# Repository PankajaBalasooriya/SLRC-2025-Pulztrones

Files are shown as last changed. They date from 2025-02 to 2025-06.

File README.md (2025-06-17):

# 🤖 SLRC Vision-Based Autonomous Robot (1st Runner-up)

This repository contains the design and codebase of our autonomous robot, developed for the **Sri Lankan Robotics Challenge (SLRC)**. Our robot was powered by a ** STM32 microcontroller and Raspberry Pi**, and it earned **1st Runner-up** in the national university category.

---

## 📸 Preview
<center>
<table>
  <tr>
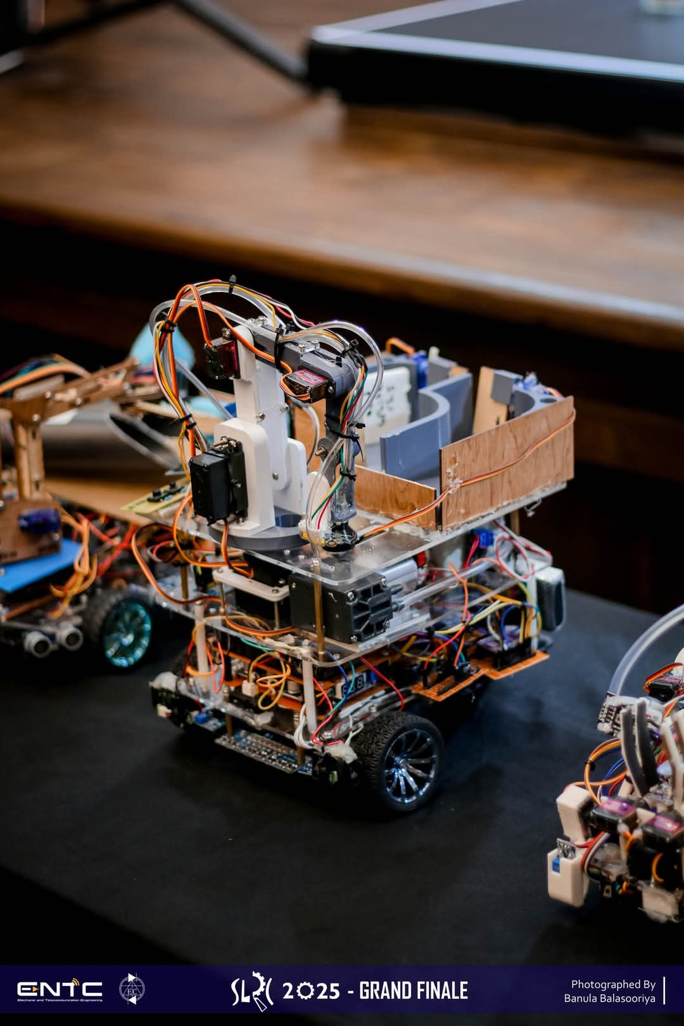
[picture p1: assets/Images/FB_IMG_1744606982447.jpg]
    <td>
  <br>
  <em>Figure 1: Final robot design for SLRC 2024</em></td>
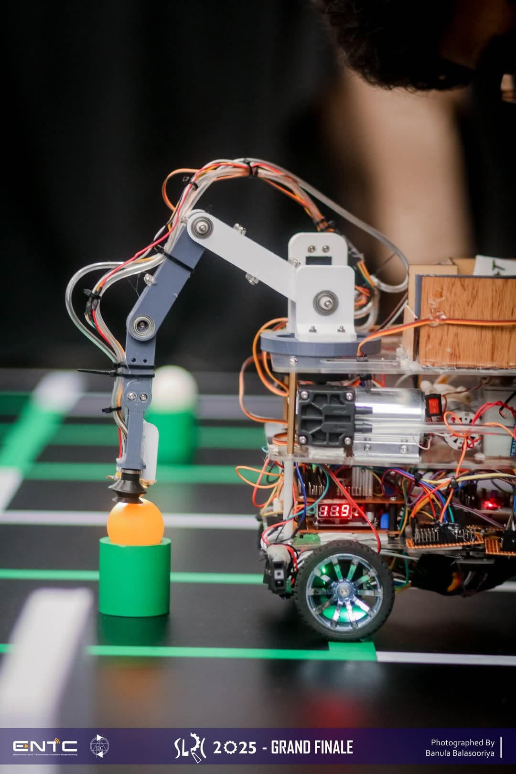
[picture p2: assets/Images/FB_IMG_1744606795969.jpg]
    <td>
  <br>
  <em>Figure 2: Color Detection using Robot Arm</em></td>
  </tr>
</table>
</center>
<p align="center">
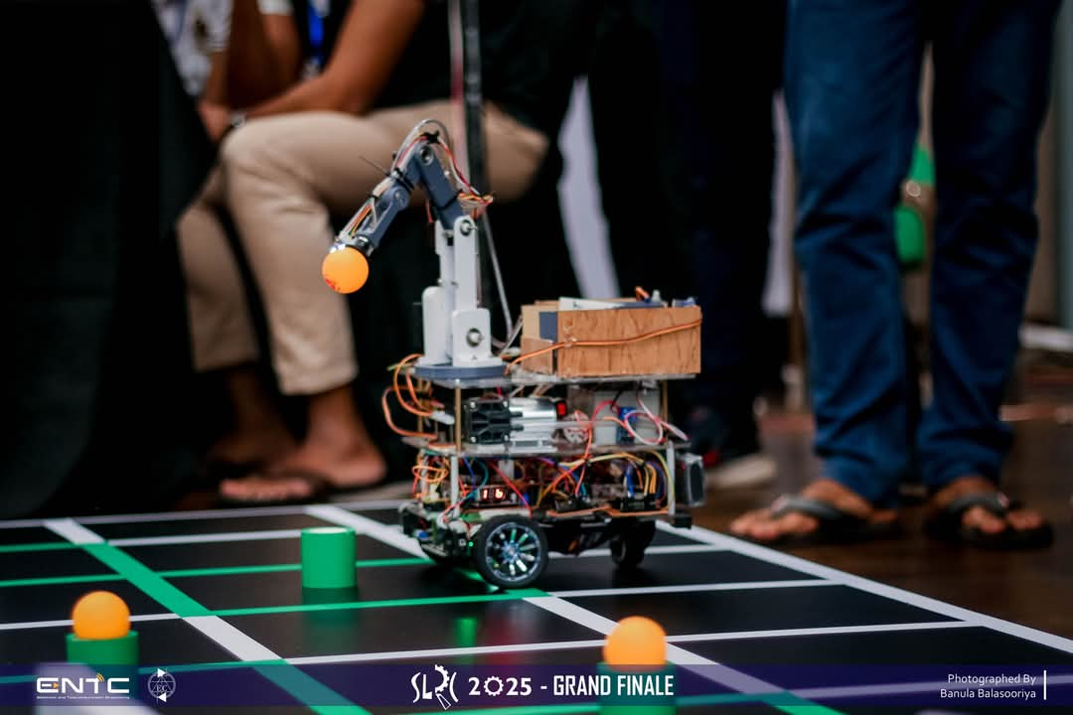
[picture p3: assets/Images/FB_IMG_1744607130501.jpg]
  
  <br>
  <em>Figure 3: Picking Balls using Robot Arm</em>
</p>

<p align="center">
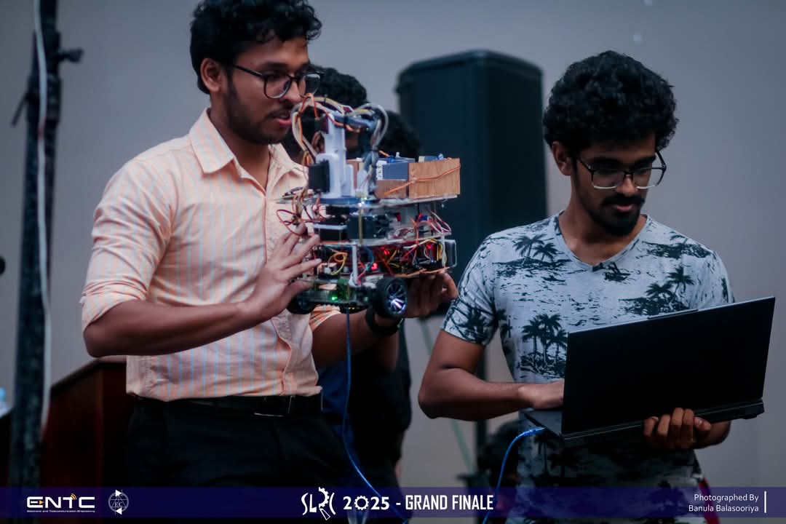
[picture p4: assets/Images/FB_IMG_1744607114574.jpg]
  
  <br>
  <em>Figure 4: Progrmming the hidden task</em>
</p>

<p align="center">
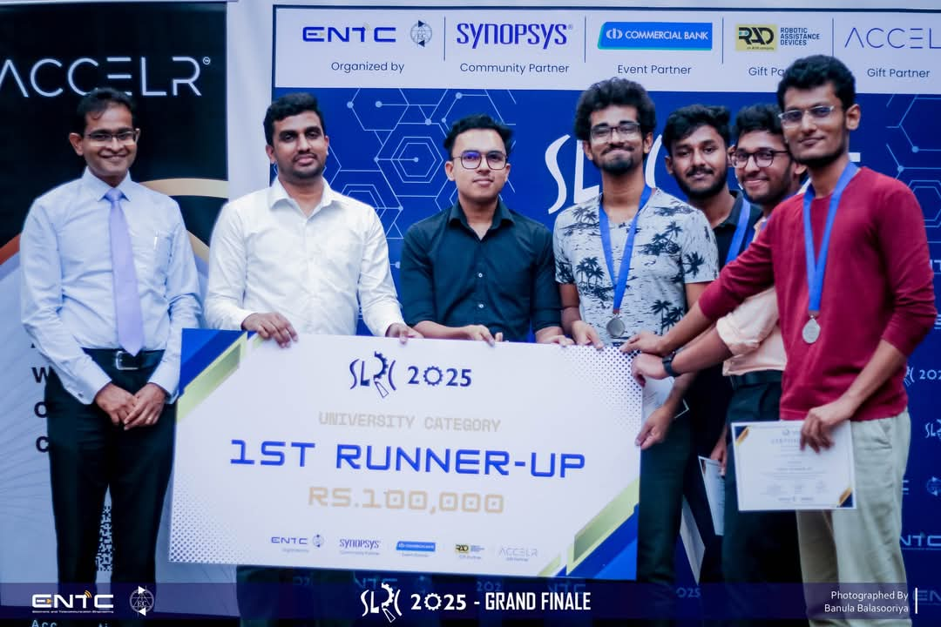
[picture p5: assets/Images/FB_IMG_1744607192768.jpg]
  
  <br>
  <em>Figure 5: Awarding Ceramony</em>
</p>

---

## 🚀 Key Features

- 🔧 Real-time control with **STM32 microcontroller**
- 🎯 Vision-based object tracking using **OpenCV** - For Elimination Round only
- 🔁 PID-based motor control
- 🧠 Modular software structure (Python + Embedded C)
- 🖥️ UART-based communication between Pi and STM32

---

## 🛠️ Hardware Components

| Component | Description |
|---|---|
| Raspberry Pi | High-level processing (vision, logic) |
| STM32 MCU | Low-level motor control |
| Motor Drivers | L298N Dual H-Bridge |
| Camera Module | Raspberry Pi Camera Module v2 |
| Chassis & Motors  | Custom-built 2WD platform |
| Power Supply | 11.1V LiPo Battery |

---

📅 **Last Updated - Codes:** `[06-04-2025]`
📅 **Last Updated - Designs:** `[06-04-2025]`

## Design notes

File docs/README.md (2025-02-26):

# 📚  Datasheets and References

| **Component** | **Datasheet / Reference Link** |
|---|---|
| **STM32F446RE** (MCU) Datasheet | [STM32F446RE Datasheet](https://www.st.com/resource/en/datasheet/stm32f446re.pdf) |
| **STM32F446RE** (MCU) User Manual | [STM32F446RE User Manual](https://www.st.com/resource/en/user_manual/um1724-stm32-nucleo64-boards-mb1136-stmicroelectronics.pdf) |
| **STM32F446RE** (MCU) Reference | [STM32F446RE Reference](https://os.mbed.com/platforms/ST-Nucleo-F446RE/) |
| **Raspberry Pi 4B** | [Raspberry Pi Datasheet](https://datasheets.raspberrypi.com/rpi4/raspberry-pi-4-datasheet.pdf) |
| **Raspberry Pi 4B** Documentation | [Raspberry Pi 4B Docs](https://www.raspberrypi.com/documentation/) |
| **Raspberry Pi 4B** BCM2711 | [BCM2711 Datasheet](https://datasheets.raspberrypi.com/bcm2711/bcm2711-peripherals.pdf) |
| **Raspberry Pi 4B** Schematics | [Raspberry Pi 4B Schematics](https://datasheets.raspberrypi.com/rpi4/raspberry-pi-4-reduced-schematics.pdf) |
| **Raspberry Pi 4B** GPIO | [Raspberry Pi GPIO](https://dnycf48t040dh.cloudfront.net/fit-in/840x473/GPIO-diagram-Raspberry-Pi-4.png) |
|||
| **PCA9685 16-Ch 12-bit PWM I2C Servo Motor Driver**  | [Adafruit Datasheet](https://cdn-learn.adafruit.com/downloads/pdf/16-channel-pwm-servo-driver.pdf) |
| **PCA9685 Datasheet**  | [PCA9685 Datasheet](https://github.com/henriheimann/stm32-hal-pca9685/blob/master/datasheet/PCA9685.pdf) |

For any updates or additional references, please keep this file updated. 🚀

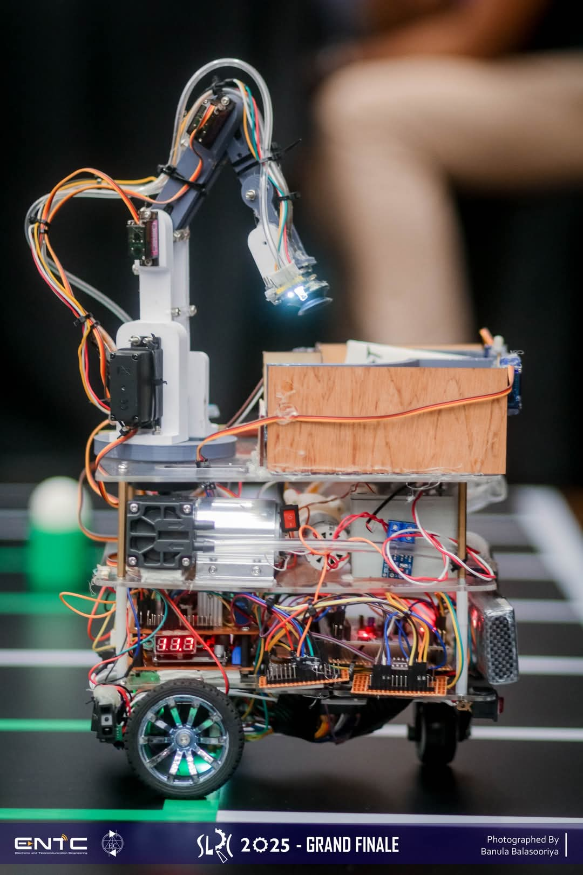
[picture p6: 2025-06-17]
assets/Images/FB_IMG_1744607050026.jpg

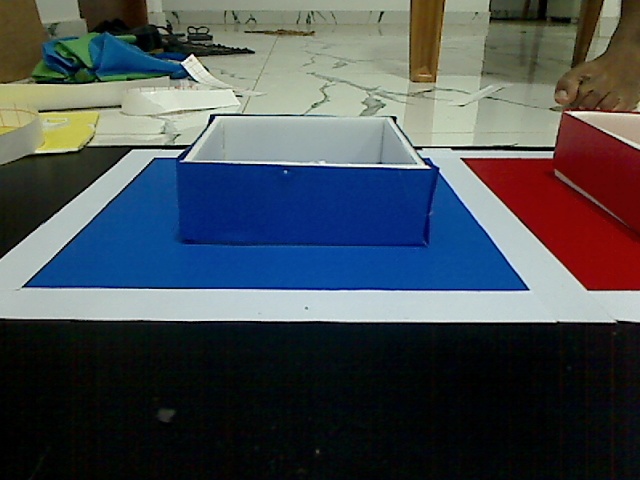
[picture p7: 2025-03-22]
software/RPI/captured_image_4.jpg

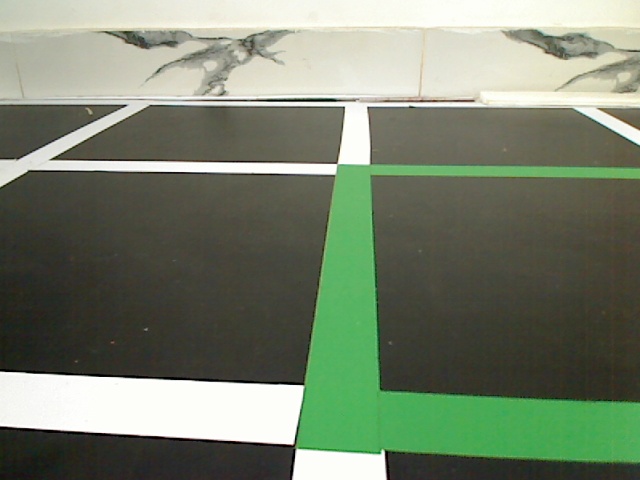
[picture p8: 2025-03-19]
software/RPI/captured_image_2.jpg

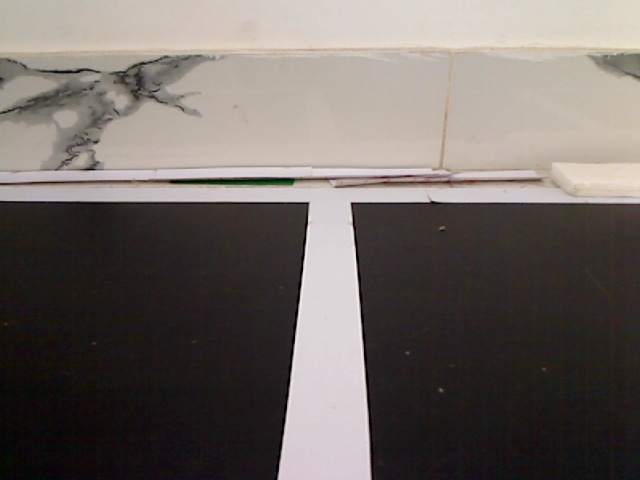
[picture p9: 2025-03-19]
software/RPI/captured_image_3.jpg

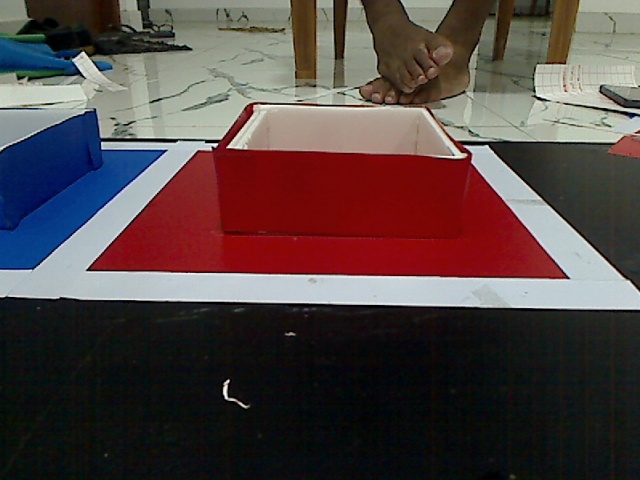
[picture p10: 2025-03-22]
software/RPI/captured_image_6.jpg

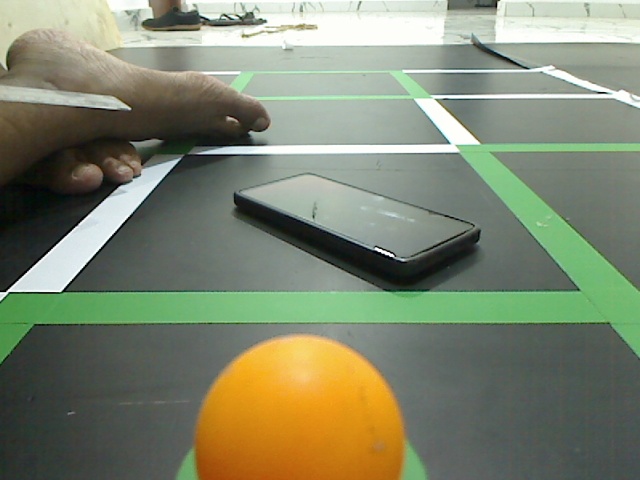
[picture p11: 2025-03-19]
software/RPI/captured_image.jpg

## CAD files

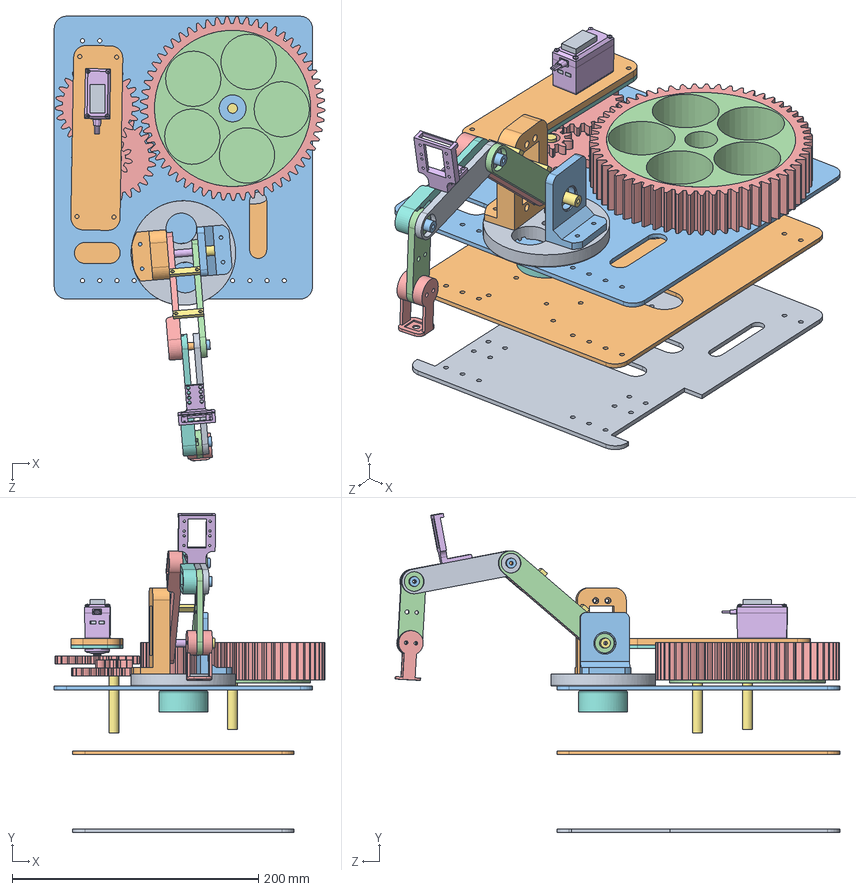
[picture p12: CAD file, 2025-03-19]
Designs/Mian Design/SLRC-2025-robot.SLDASM
219.9 x 259.3 x 361.5 mm
Bottom-plate
Mid-plate
Top-plate
Storage Gear
spur gear_ai x 4
gear bearing shaft x 2
vertical servo mount low gear
base
big servo holder
part A
part C
part B
part E
part F
Part G
Part I
Part J
part K x 2
Part L
part M
camera holder
part N x 2
Part P
MG90-servo
small servo mount

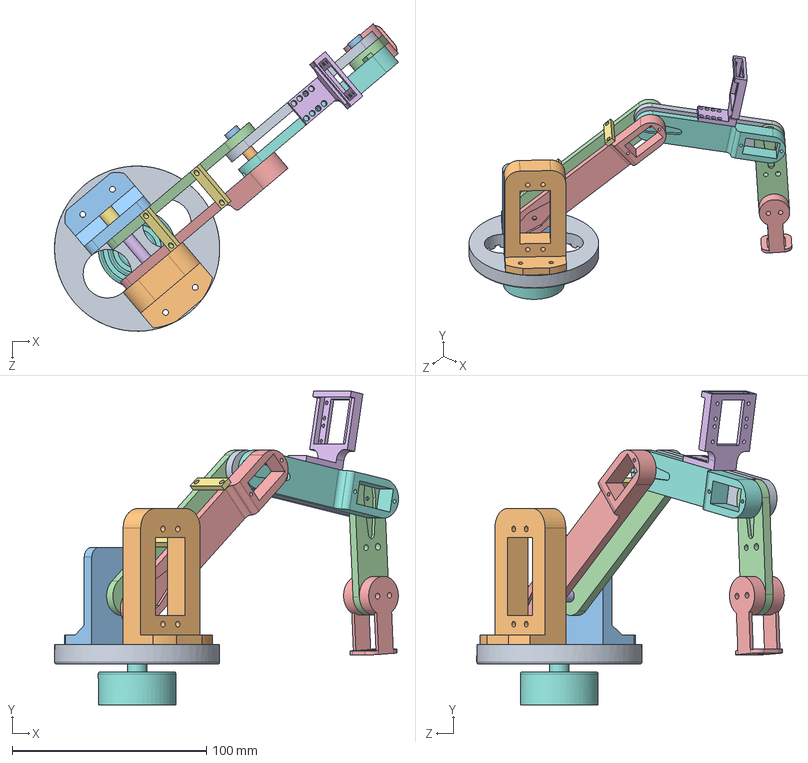
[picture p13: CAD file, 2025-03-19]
Designs/Arm design/Assem1.SLDASM
176.9 x 161.4 x 158.2 mm
base
big servo holder
part A
part C
part B
part E
part F
Part G
Part I
Part J
part K x 2
Part L
part M
camera holder
part N x 2
Part P

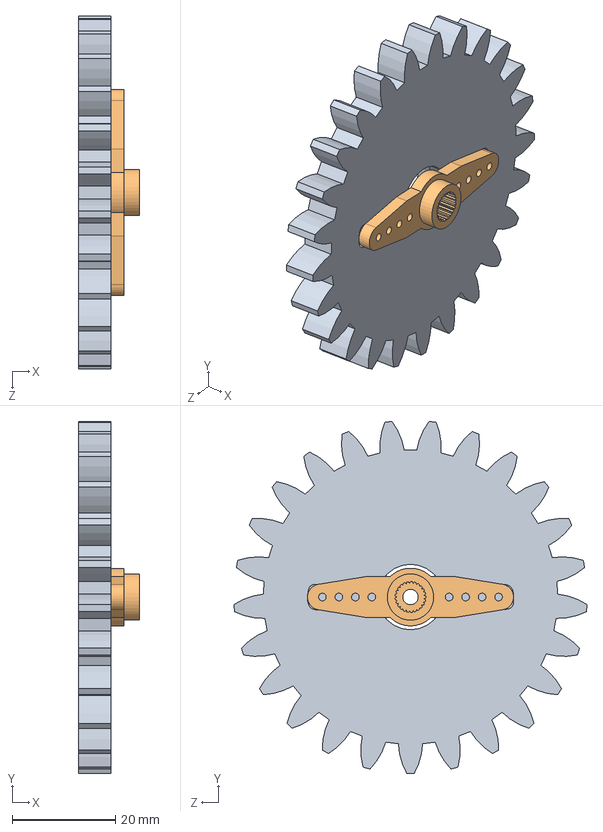
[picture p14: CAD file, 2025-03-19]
Designs/Ball Storage/Gear with servo connector grove.SLDASM
11.9 x 68.4 x 68.5 mm

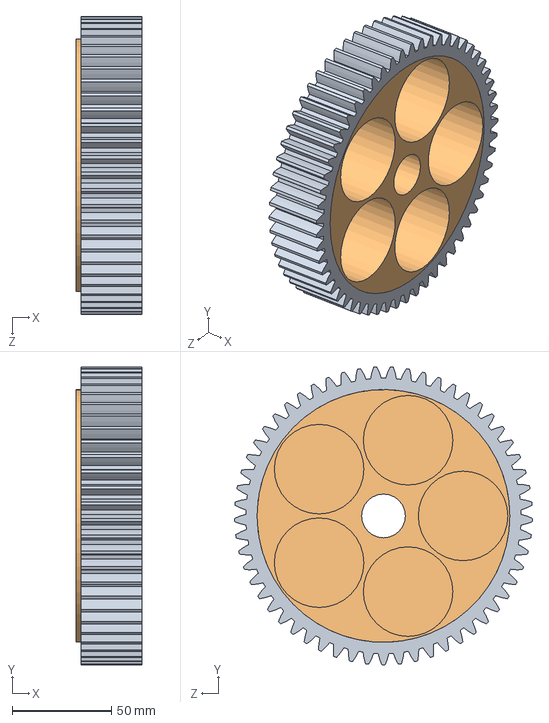
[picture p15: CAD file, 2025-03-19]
Designs/Ball Storage/Boll Storage gear Assemblt.SLDASM
33.0 x 149.8 x 149.8 mm
spur gear_ai
Storage Gear

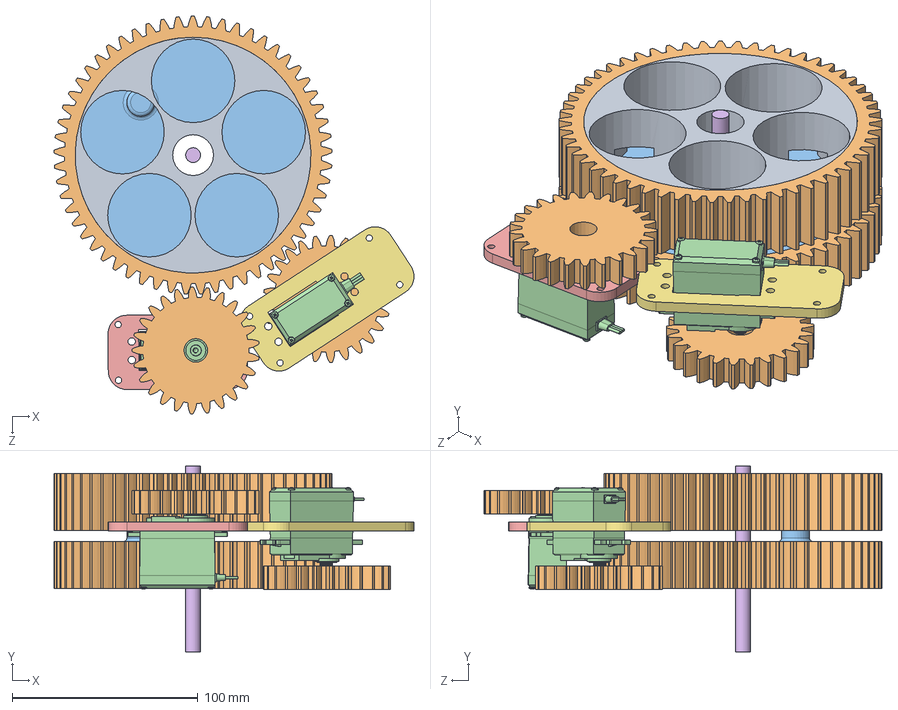
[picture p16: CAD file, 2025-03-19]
Designs/Ball Storage/Storage Gear Ass.SLDASM
193.9 x 100.0 x 214.4 mm
Storage Gear
spur gear_ai x 4
Pop up Gear
mg996R x 2
vertical servo mount high gear
gear bearing shaft
vertical servo mount low gear

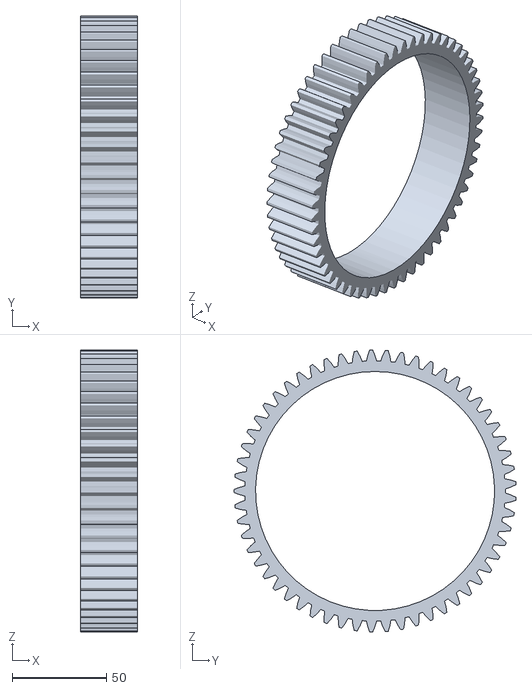
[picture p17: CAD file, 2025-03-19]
Designs/3D Prints/Boll Storage gear Assemblt - spur gear_ai-1.STL
30.5 x 149.8 x 149.8

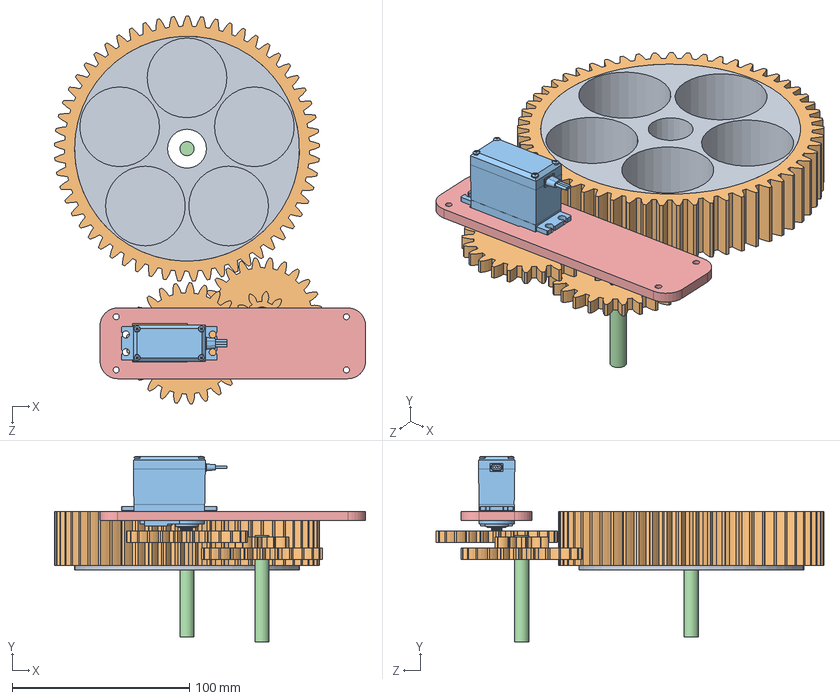
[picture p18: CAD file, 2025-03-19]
Designs/Ball Storage/Storage Gear only Ass.SLDASM
175.8 x 104.8 x 219.1 mm
Storage Gear
spur gear_ai x 4
mg996R
gear bearing shaft x 2
vertical servo mount low gear

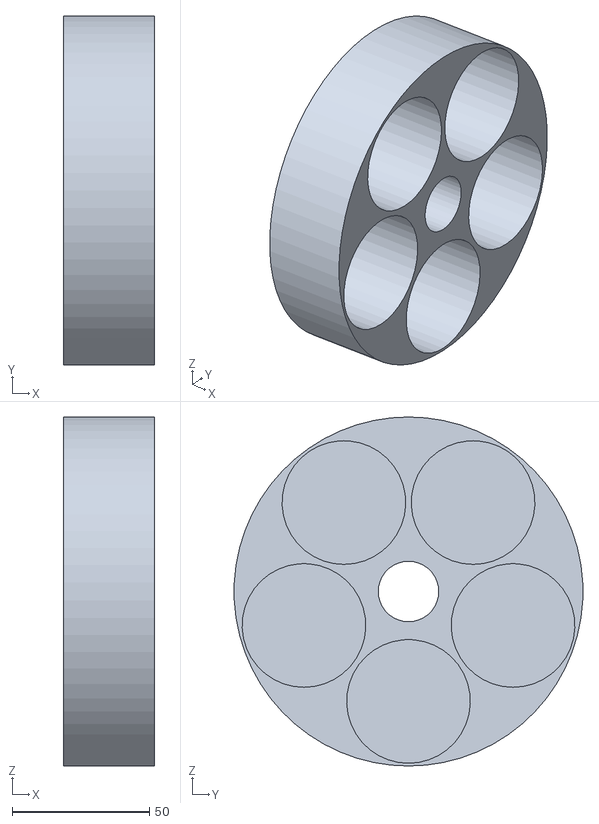
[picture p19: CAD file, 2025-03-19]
Designs/3D Prints/Boll Storage gear Assemblt - Storage Gear-1.STL
33.0 x 126.8 x 127.0

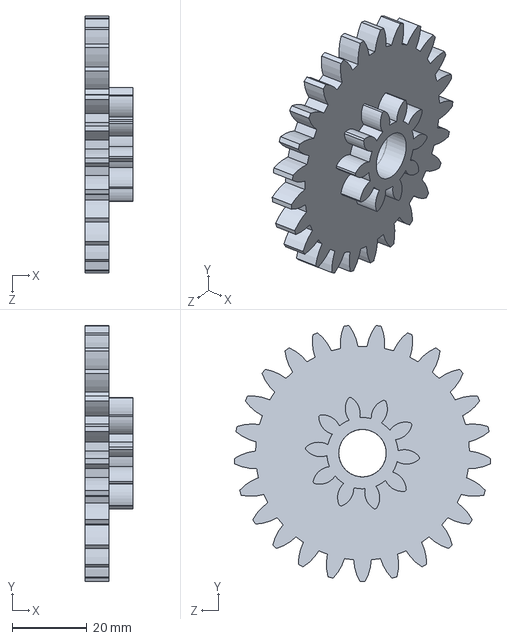
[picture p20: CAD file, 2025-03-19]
Designs/Ball Storage/Coupling Gear.SLDASM
12.7 x 68.4 x 68.5 mm
spur gear_ai x 2

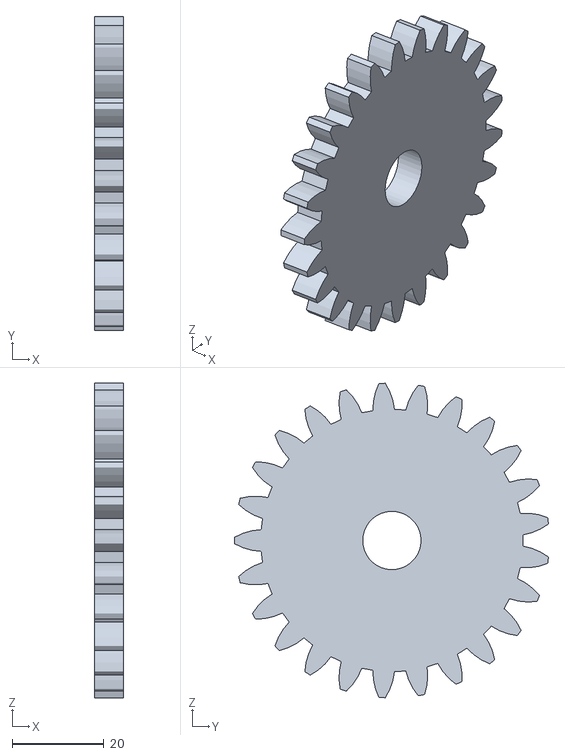
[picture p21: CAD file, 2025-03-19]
Designs/3D Prints/Coupling Gear - spur gear_ai-1.STL
6.35 x 68.4 x 68.5

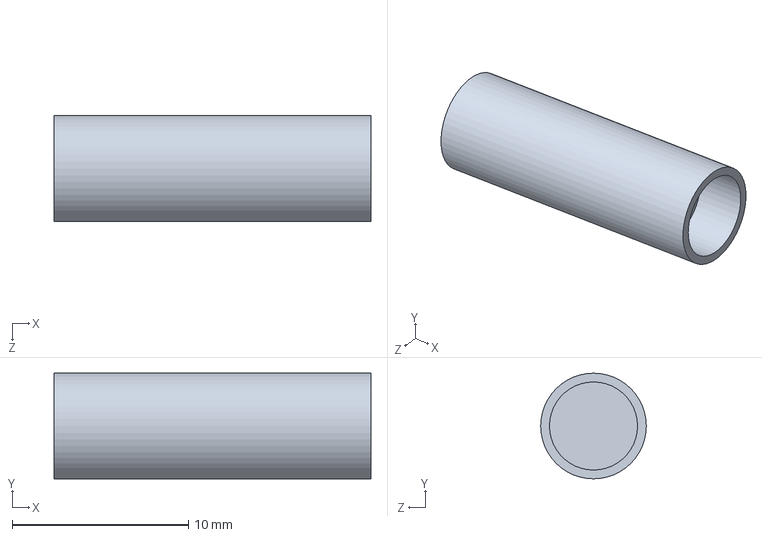
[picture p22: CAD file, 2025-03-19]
Designs/Arm design/part E.SLDPRT
18.0 x 6.00 x 6.00 mm

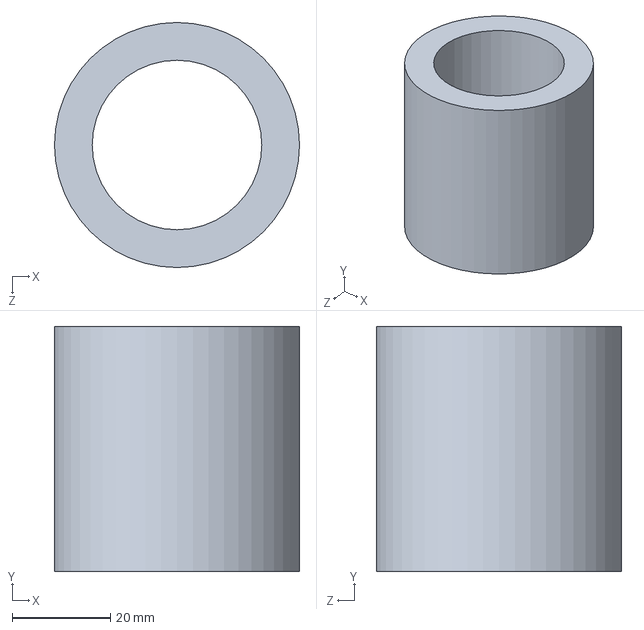
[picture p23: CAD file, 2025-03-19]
Designs/Assets/Ball holder plant.SLDPRT
50.0 x 50.0 x 50.0 mm

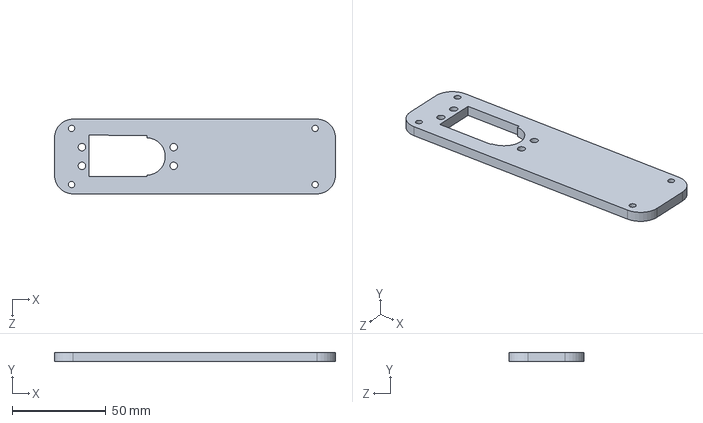
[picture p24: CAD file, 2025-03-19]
Designs/Ball Storage/vertical servo mount low gear.SLDPRT
150.0 x 5.00 x 40.0 mm

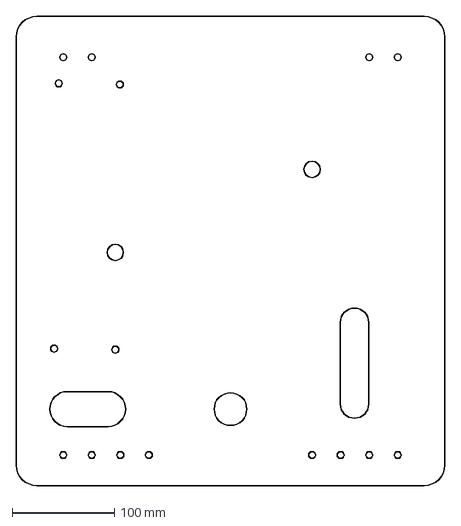
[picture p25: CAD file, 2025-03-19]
Designs/Laser Cuts/Top-plate.DXF
420.0 x 460.0 mm

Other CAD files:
Designs/3D Prints/Part P.STL
Designs/Laser Cuts/Bottom-plate.DXF
Designs/Mian Design/Bottom Base Plate.SLDPRT
Designs/3D Prints/vertical servo mount low gear.STL
Designs/3D Prints/Ball holder plant.STL
Designs/3D Prints/Coupling Gear - spur gear_ai-2.STL
Designs/3D Prints/small servo mount.STL
Designs/3D Prints/spur gear_ai_with servo_connecton.STL
Designs/Arm design/Part G.SLDPRT
Designs/Arm design/Part I.SLDPRT
Designs/Arm design/Part J.SLDPRT
Designs/Arm design/Part L.SLDPRT
Designs/Arm design/Part P.SLDPRT
Designs/Arm design/Part1.SLDPRT
Designs/Arm design/base.SLDPRT
Designs/Arm design/big servo holder 2.SLDPRT
Designs/Arm design/big servo holder.SLDPRT
Designs/Arm design/camera holder.SLDPRT
Designs/Arm design/part A.SLDPRT
Designs/Arm design/part B.SLDPRT
Designs/Arm design/part C.SLDPRT
Designs/Arm design/part D.SLDPRT
Designs/Arm design/part F.SLDPRT
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

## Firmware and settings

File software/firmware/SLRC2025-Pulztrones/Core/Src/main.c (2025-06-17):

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
/* Includes ------------------------------------------------------------------*/
#include "main.h"

/* USER CODE BEGIN Includes */
#include "encoders.h"
#include "motors.h"
#include "pca9685.h"
#include "math.h"
#include <string.h>
#include <stdio.h>
#include "servo.h"
#include "analog_mux.h"
#include "raykha.h"
#include "buzzer.h"
#include "vl53l0x_api.h"
#include "ssd1306.h"
#include "fonts.h"
#include "bitmap.h"
#include "uartcom.h"
#include "systick.h"
#include "motion.h"
#include "profile.h"
#include "controller.h"
#include "sensors.h"
#include "string.h"
#include "stdio.h"
#include "robot.h"
#include "tasks.h"
#include "ballstorage.h"
#include "arm_controller.h"
#include "PCA9548A.h"
#include "TCS3472.h"
#include "irs.h"
#include "display.h"
#include "box_manupilation.h"




/* USER CODE END Includes */

/* USER CODE BEGIN PD */
#define BUFFER_SIZE 50

/* USER CODE END PD */

ADC_HandleTypeDef hadc1;

I2C_HandleTypeDef hi2c1;
I2C_HandleTypeDef hi2c2;

TIM_HandleTypeDef htim1;
TIM_HandleTypeDef htim2;
TIM_HandleTypeDef htim3;

UART_HandleTypeDef huart2;
UART_HandleTypeDef huart3;
UART_HandleTypeDef huart6;
DMA_HandleTypeDef hdma_usart6_rx;

/* USER CODE BEGIN PV */
volatile uint8_t systick_function_enabled = 0;

int16_t left_counts = 0;
int16_t right_counts = 0;


RAYKHA_Calibration raykha_calibration;
uint8_t calibration_complete = 0;


volatile uint8_t task_ready = 0;  // Global flag

extern uint16_t r_line, g_line, b_line, c_line;
extern uint16_t r_obj, g_obj, b_obj, c_obj;
extern Color line_color, object_color;

char buffer[100];

volatile TaskType currentTask = TASK_NONE;

extern volatile SensorChannel lfs, lrs, fs, rfs, rrs;
extern volatile uint8_t see_front_wall;
extern volatile uint8_t see_box;


/* USER CODE END PV */

void SystemClock_Config(void);
static void MX_GPIO_Init(void);
static void MX_DMA_Init(void);
static void MX_USART2_UART_Init(void);
static void MX_TIM1_Init(void);
static void MX_TIM2_Init(void);
static void MX_I2C2_Init(void);
static void MX_USART3_UART_Init(void);
static void MX_USART6_UART_Init(void);
static void MX_ADC1_Init(void);
static void MX_I2C1_Init(void);
static void MX_TIM3_Init(void);
/* USER CODE BEGIN 0 */
Motion motion;
Profile forward_profile;
Profile rotation_profile;
Controller controller;


i2c_mux_t mux = {
    .hi2c = &hi2c1,   // Assign I2C1 handle
    .rst_port = NULL,  // No reset pin used (set if needed)
    .rst_pin = 0,      // No reset pin used
    .addr_offset = 0   // Change if the address is modified by A0-A2 pins
};



/* USER CODE END 0 */

/**
  * @brief  The application entry point.
  * @retval int
  */
int main(void)
{

	/* MCU Configuration--------------------------------------------------------*/

	/* Reset of all peripherals, Initializes the Flash interface and the Systick. */
	HAL_Init();

	/* Configure the system clock */
	SystemClock_Config();

	/* Initialize all configured peripherals */
	MX_GPIO_Init();
	MX_DMA_Init();
	MX_USART2_UART_Init();
	MX_TIM1_Init();
	MX_TIM2_Init();
	MX_I2C2_Init();
	MX_USART3_UART_Init();
	MX_USART6_UART_Init();
	MX_ADC1_Init();
	MX_I2C1_Init();
	MX_TIM3_Init();
	/* USER CODE BEGIN 2 */
	HAL_TIM_Encoder_Start(&htim1, TIM_CHANNEL_ALL);
	HAL_TIM_Encoder_Start(&htim2, TIM_CHANNEL_ALL);

	HAL_TIM_PWM_Start(&htim3, TIM_CHANNEL_1);
	HAL_TIM_PWM_Start(&htim3, TIM_CHANNEL_2);
	HAL_TIM_PWM_Start(&htim3, TIM_CHANNEL_3);
	HAL_TIM_PWM_Start(&htim3, TIM_CHANNEL_4);

	turn_on_air_pump();
	turn_on_water_pump();

	HAL_Delay(5000);
	turn_off_air_pump();


	/*--------------------- OLED Display --------------------------------*/
	Init_Display();


	/*---------------------Delay--------------------------------*/
	Delay_Init();
	/*-------------------------------------------------------------------*/

	/*---------------------Servos--------------------------------*/
	// Initialize servo system
	Servo_Init(50);  // 50Hz frequency for servos
	// Initialize arm
	Arm_Init();

	// Init ball storage
	init_ball_storage();


	/*-------------------------------------------------------------------*/

	Controller_Init(&controller);
	Profile_Reset(&forward_profile);
	Profile_Reset(&rotation_profile);
	Motion_Init(&motion, &controller, &forward_profile, &rotation_profile);
	Controller_ResetControllers(&controller);

	Buzzer_UniquePattern();

	Buzzer_Toggle(200);
	HAL_Delay(2000);
	/*--------------- Raykha calibration ----------------------------------*/
	//RAYKHA_Calibrate(&raykha_calibration, RAYKHA_LINE_WHITE);
	/*-------------------------------------------------------------------*/
	HAL_Delay(2000);
	//Buzzer_Toggle(200);


	/*----------------- Begin color sensor init--------------------------------*/
	Buzzer_Toggle(100);
	//init_color_sensors();
	//caliberate_color_sensors();

	/*--------------- End color sensor init-----------------------------------*/

	//display_big_number(2);





  //---------------- End of Motion controller tests---------------------------------------------
	//box_manupilation();
	//selectTask();

  /* USER CODE END 2 */

  /* Infinite loop */
  /* USER CODE BEGIN WHILE */
  while (1)
  {
    /* USER CODE END WHILE */



    /* USER CODE BEGIN 3 */

	  //runCurrentTask();
	  //RangeAllIRSensors();

//	  Color Ball_color = GetBallColor();
//	  HAL_Delay(600);


//	  if (task_ready){
//		  task_ready = 0;
//
//		HAL_Delay(200);
//
//	EnableSysTickFunction();
//
//		runCurrentTask(TASK_PLANTATION);
//
//		Buzzer_Toggle(500);
//
//		runCurrentTask(TASK_SORTING_POTATOS);
//
//		Buzzer_TaskCompletion();
//
//	  }


	  left_counts = getLeftEncoderCounts();
	  right_counts = getRightEncoderCounts();
	  //UART_Transmit_IR(&huart3, left_counts, right_counts);

	  setMotorLPWM(0.5);
	  setMotorRPWM(0.5);
  }
  /* USER CODE END 3 */
}

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


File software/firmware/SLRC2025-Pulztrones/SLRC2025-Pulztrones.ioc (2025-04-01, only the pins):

Mcu.UserName=STM32F446RETx
PA0-WKUP.GPIO_Label=RightEncoderCh1 
PA0-WKUP.Signal=S_TIM2_CH1_ETR
PA1.GPIO_Label=RightEncoderCh2 
PA1.Signal=S_TIM2_CH2
PA13.GPIO_Label=TMS
PA13.Signal=SYS_JTMS-SWDIO
PA14.GPIO_Label=TCK
PA14.Signal=SYS_JTCK-SWCLK
PA2.GPIO_Label=USART_TX
PA2.Signal=USART2_TX
PA3.GPIO_Label=USART_RX
PA3.Signal=USART2_RX
PA5.GPIO_Label=LD2 [Green Led]
PA5.Signal=GPIO_Output
PA6.Signal=S_TIM3_CH1
PA7.Signal=S_TIM3_CH2
PA8.GPIO_Label=LeftEncoderCh1 
PA8.Signal=S_TIM1_CH1
PA9.GPIO_Label=LeftEncoderCh2
PA9.Signal=S_TIM1_CH2
PB0.Signal=S_TIM3_CH3
PB1.Signal=S_TIM3_CH4
PB10.Signal=I2C2_SCL
PB12.GPIO_Label=S0
PB12.Signal=GPIO_Output
PB13.GPIO_Label=S1
PB13.Signal=GPIO_Output
PB14.GPIO_Label=S2
PB14.Signal=GPIO_Output
PB15.GPIO_Label=S3
PB15.Signal=GPIO_Output
PB3.GPIO_Label=SWO
PB3.Signal=SYS_JTDO-SWO
PB6.Signal=I2C1_SCL
PB7.Signal=I2C1_SDA
PC0.GPIO_Label=IR_ADC
PC0.Signal=ADCx_IN10
PC1.GPIO_Label=AIRPUMP
PC1.Signal=GPIO_Output
PC10.Signal=USART3_TX
PC11.Signal=GPXTI11
PC12.Signal=I2C2_SDA
PC13.GPIO_Label=B1 [Blue PushButton]
PC13.Signal=GPXTI13
PC14-OSC32_IN.Signal=RCC_OSC32_IN
PC15-OSC32_OUT.Signal=RCC_OSC32_OUT
PC2.GPIO_Label=WATERPUMP
PC2.Signal=GPIO_Output
PC3.Signal=GPXTI3
PC5.Signal=USART3_RX
PC6.Signal=USART6_TX
PC7.Signal=USART6_RX
PH0-OSC_IN.Signal=RCC_OSC_IN
PH1-OSC_OUT.Signal=RCC_OSC_OUT

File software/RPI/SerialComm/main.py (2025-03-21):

#!/usr/bin/env python3
"""
Raspberry Pi UART Communication for Robot Control
This script handles computer vision tasks and communicates with STM32 via UART
"""

import serial
import time
import threading
import cv2
import numpy as np

from adj_line_color import detect_adjacent_line_color

# Communication protocol definitions
START_MARKER = b'<'
END_MARKER = b'>'

# Command IDs
CMD_LINE_DETECTED = 0x01
CMD_GRID_POSITION = 0x02
CMD_COLOR_DETECTED = 0x03

CMD_LINE_COLOR = 0x04


CMD_START_LINE_FOLLOWING = 0x31
CMD_START_GRID_NAVIGATION = 0x32
CMD_START_COLOR_DETECTION = 0x33

CMD_START_LINE_COLOR_DETECTION = 0x34


CMD_STOP = 0x50

class RobotComm:
    def __init__(self, serial_port='/dev/serial0', baud_rate=115200):
        """Initialize UART communication with STM32"""
        self.serial = serial.Serial(
            port=serial_port,
            baudrate=baud_rate,
            parity=serial.PARITY_NONE,
            stopbits=serial.STOPBITS_ONE,
            bytesize=serial.EIGHTBITS,
            timeout=1
        )
        
        # Initialize state variables
        self.rx_state = 'WAITING_FOR_START'
        self.rx_buffer = bytearray()
        self.rx_cmd = 0
        self.rx_length = 0
        
        # Initialize operation mode
        self.current_mode = None
        
        # Initialize camera
        self.camera = cv2.VideoCapture(0)  # Use camera index 0
        if not self.camera.isOpened():
            print("Error: Could not open camera")
        
        # Set camera resolution
        self.camera.set(cv2.CAP_PROP_FRAME_WIDTH, 640)
        self.camera.set(cv2.CAP_PROP_FRAME_HEIGHT, 480)
        
        # Flag to control processing threads
        self.running = True
        
        # Start receive thread
        self.rx_thread = threading.Thread(target=self.receive_data)
        self.rx_thread.daemon = True
        self.rx_thread.start()
        
        # Vision processing thread
        self.vision_thread = None
        
        print("Robot communication initialized")
    
    def __del__(self):
        """Clean up resources on object destruction"""
        self.running = False
        if self.serial.is_open:
            self.serial.close()
        if self.camera.isOpened():
            self.camera.release()
    
    def receive_data(self):
        """Thread function to receive and process data from STM32"""
        while self.running:
            if self.serial.in_waiting > 0:
                # Read one byte
                rx_byte = self.serial.read(1)
                
                # State machine for packet reception
                if self.rx_state == 'WAITING_FOR_START':
                    if rx_byte == START_MARKER:
                        self.rx_state = 'WAITING_FOR_CMD'
                
                elif self.rx_state == 'WAITING_FOR_CMD':
                    self.rx_cmd = int.from_bytes(rx_byte, byteorder='little')
                    self.rx_state = 'WAITING_FOR_LENGTH'
                
                elif self.rx_state == 'WAITING_FOR_LENGTH':
                    self.rx_length = int.from_bytes(rx_byte, byteorder='little')
                    self.rx_buffer = bytearray()
                    if self.rx_length > 0:
                        self.rx_state = 'RECEIVING_DATA'
                    else:
                        self.rx_state = 'WAITING_FOR_END'
                
                elif self.rx_state == 'RECEIVING_DATA':
                    self.rx_buffer.extend(rx_byte)
                    if len(self.rx_buffer) >= self.rx_length:
                        self.rx_state = 'WAITING_FOR_END'
                
                elif self.rx_state == 'WAITING_FOR_END':
                    if rx_byte == END_MARKER:
                        # Process complete packet
                        self.process_command()
                    # Reset state machine for next packet
                    self.rx_state = 'WAITING_FOR_START'
            
            # Sleep briefly to reduce CPU usage
            time.sleep(0.001)
    
    def process_command(self):
        """Process received command from STM32"""
        print(f"Received command: {self.rx_cmd}")
        
        if self.rx_cmd == CMD_START_LINE_FOLLOWING:
            # Stop any existing vision processing
            self.stop_vision_processing()
            # Start line following mode
            self.current_mode = 'line_following'
            self.vision_thread = threading.Thread(target=self.line_following_task)
            self.vision_thread.daemon = True
            self.vision_thread.start()
            
        elif self.rx_cmd == CMD_START_GRID_NAVIGATION:
            # Stop any existing vision processing
            self.stop_vision_processing()
            # Extract target coordinates
            if len(self.rx_buffer) >= 2:
                target_x = self.rx_buffer[0]
                target_y = self.rx_buffer[1]
                # Start grid navigation mode
                self.current_mode = 'grid_navigation'
                self.vision_thread = threading.Thread(target=self.grid_navigation_task, 
                                                    args=(target_x, target_y))
                self.vision_thread.daemon = True
                self.vision_thread.start()
            
        elif self.rx_cmd == CMD_START_COLOR_DETECTION:
            # Stop any existing vision processing
            self.stop_vision_processing()
            # Start color detection mode
            self.current_mode = 'color_detection'
            self.vision_thread = threading.Thread(target=self.color_detection_task)
            self.vision_thread.daemon = True
            self.vision_thread.start()

        elif self.rx_cmd == CMD_START_LINE_COLOR_DETECTION:
            # Stop any existing vision processing
            self.stop_vision_processing()
            # Start color detection mode
            self.current_mode = 'line_color_detection'
            self.vision_thread = threading.Thread(target=self.line_color_detection_task)
            self.vision_thread.daemon = True
            self.vision_thread.start()
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

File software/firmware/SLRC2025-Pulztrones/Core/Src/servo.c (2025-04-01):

/**
  ******************************************************************************
  * @file           : servo.c
  * @brief          : Servo control abstraction implementation
  ******************************************************************************
  */

/* Includes ------------------------------------------------------------------*/
#include "servo.h"
#include <string.h>

/* Private variables ---------------------------------------------------------*/
static Servo_t servos[MAX_SERVOS];
static uint8_t servoCount = 0;
static uint8_t isInitialized = 0;

/* Function Implementations --------------------------------------------------*/

/**
  * @brief  Initialize the servo control system
  * @param  frequency: PWM frequency for the servos (typically 50Hz)
  * @retval None
  */
void Servo_Init(uint16_t frequency)
{
    if (isInitialized)
        return;

    // Initialize PCA9685 with the specified frequency
    PCA9685_Init(frequency);

    // Clear the servo array
    memset(servos, 0, sizeof(servos));
    servoCount = 0;
    isInitialized = 1;
}

/**
  * @brief  Register a new servo with the system
  * @param  channel: PCA9685 channel (0-15)
  * @param  name: Optional name for the servo (can be NULL)
  * @param  minAngle: Minimum angle limit (0-180)
  * @param  maxAngle: Maximum angle limit (0-180)
  * @retval int: Servo ID (0 to MAX_SERVOS-1) or -1 if error
  */
int Servo_Register(uint8_t channel, const char* name, float minAngle, float maxAngle, float init_angle)
{
    // Check if initialized
    if (!isInitialized)
        return -1;

    // Check if we've reached maximum servo count
    if (servoCount >= MAX_SERVOS)
        return -1;

    // Check if channel is valid
    if (channel >= MAX_SERVOS)
        return -1;

    // Check if the channel is already in use
    for (int i = 0; i < servoCount; i++) {
        if (servos[i].initialized && servos[i].channel == channel)
            return -1;
    }

    // Validate angle limits
    if (minAngle < SERVO_ANGLE_MIN) minAngle = SERVO_ANGLE_MIN;
    if (maxAngle > SERVO_ANGLE_MAX) maxAngle = SERVO_ANGLE_MAX;
    if (minAngle >= maxAngle) return -1;

    // Register the servo
    int servoId = servoCount;
    servos[servoId].channel = channel;
    servos[servoId].minAngle = minAngle;
    servos[servoId].maxAngle = maxAngle;
    //servos[servoId].currentAngle = (minAngle + maxAngle) / 2.0f;  // Center position
    servos[servoId].currentAngle = init_angle;
    servos[servoId].initialized = 1;

    // Set optional name
    if (name != NULL) {
        strncpy(servos[servoId].name, name, sizeof(servos[servoId].name) - 1);
        servos[servoId].name[sizeof(servos[servoId].name) - 1] = '\0';  // Ensure null termination
    } else {
        snprintf(servos[servoId].name, sizeof(servos[servoId].name), "Servo%d", servoId);
    }

    // Update servo count
    servoCount++;

    // Move servo to center position
    PCA9685_SetServoAngle(channel, servos[servoId].currentAngle);

    return servoId;
}

/**
  * @brief  Set servo position by ID
  * @param  servoId: ID returned from Servo_Register
  * @param  angle: Desired angle in degrees
  * @retval int: 0 if successful, -1 if error
  */
int Servo_SetAngle(int servoId, float angle)
{
    // Check if servo ID is valid
    if (servoId < 0 || servoId >= servoCount || !servos[servoId].initialized)
        return -1;

    // Clamp angle to servo limits
    if (angle < servos[servoId].minAngle)
        angle = servos[servoId].minAngle;
    if (angle > servos[servoId].maxAngle)
        angle = servos[servoId].maxAngle;

    // Update current angle
    servos[servoId].currentAngle = angle;

    // Set servo position
    PCA9685_SetServoAngle(servos[servoId].channel, angle);

    return 0;
}

/**
  * @brief  Set servo position by name
  * @param  name: Name of the servo
  * @param  angle: Desired angle in degrees
  * @retval int: 0 if successful, -1 if error
  */
int Servo_SetAngleByName(const char* name, float angle)
{
    if (name == NULL)
        return -1;

    int servoId = Servo_GetIdByName(name);

    if (servoId >= 0)
        return Servo_SetAngle(servoId, angle);
    else
        return -1;
}

/**
  * @brief  Get current angle of a servo
  * @param  servoId: ID returned from Servo_Register
  * @retval float: Current angle in degrees or -1.0f if error
  */
float Servo_GetAngle(int servoId)
{
    // Check if servo ID is valid
    if (servoId < 0 || servoId >= servoCount || !servos[servoId].initialized)
        return -1.0f;

    return servos[servoId].currentAngle;
}

/**
  * @brief  Get servo ID by name
  * @param  name: Name of the servo
  * @retval int: Servo ID or -1 if not found
  */
int Servo_GetIdByName(const char* name)
{
    if (name == NULL)
        return -1;

    // Search for servo with the given name
    for (int i = 0; i < servoCount; i++) {
        if (servos[i].initialized && strcmp(servos[i].name, name) == 0)
            return i;
    }

    return -1;
}

/**
  * @brief  Reset all servos to center position (90 degrees)
  * @retval None
  */
void Servo_ResetAll(void)
{
    for (int i = 0; i < servoCount; i++) {
        if (servos[i].initialized) {
            float centerAngle = (servos[i].minAngle + servos[i].maxAngle) / 2.0f;
            Servo_SetAngle(i, centerAngle);
            HAL_Delay(10);  // Small delay between movements
        }
    }
}


void Turn360Servo()
{
  float pwmValue;


  pwmValue = 295.00;//299

  // Set PWM with calculated value
  PCA9685_SetPWM(14, 0, (uint16_t)pwmValue);
}

void Stop360Servo()
{
	float pwmValue;


	  pwmValue = 305;

	  // Set PWM with calculated value
	  PCA9685_SetPWM(14, 0, (uint16_t)pwmValue);
}

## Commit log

2025-02-12 Add initial project firmware for stm32 and configuration files
2025-02-15 Add datasheets and reference links for STM32F446RE and Raspberry Pi 4B
2025-02-15 Add encoder and motor control headers and implementations; update README with pin mappings
2025-02-20 Design files Upload
    [Pop up Gear.SLDPRT, Storage Gear Ass.SLDASM, Storage Gear.SLDPRT]
2025-02-21 Add initial source files for SysTick functionality and pca9685 servo driver
2025-02-23 ball storage updated
    [Pop up Gear.SLDPRT, Servo mount new.SLDPRT, Storage Gear Ass.SLDASM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]
2025-02-26 Add USART6 and DMA2 interrupt handlers; update project settings and metadata
2025-02-26 test uart send and recive functions
2025-02-28 Finalized servo control and pca9685 driver
2025-03-14 Update raykha position calculation and increase sensor count; adjust motor PWM control logic
2025-03-15 Ball storage 1st 3D print iteration
    [Assem1.SLDASM, Ball holder plant.SLDPRT, Ball holder plant.STL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]
2025-03-16 add VL53l0x driver
2025-03-16 add buzzer control functionality with on, off, toggle, and unique pattern features
    [buzzer.c]
2025-03-17 add configuration and driver files for SSD1306 and VL53L0X, UARTbluetooth
2025-03-17 Add velocity and distance calculations using encoder data
2025-03-18 Add functions for 360-degree servo control and update sensor handling
2025-03-19 Tuned STEERING KP and KD Constants for line follow
2025-03-20 Add new source files and update project settings for STM32 firmware
2025-03-21 Implement ball storage rotation logic with encoder feedback and interrupt handling
2025-03-21 add line color detection method and add debug prints for color detection
2025-03-21 Update robot and config files for line color detection and add new constants for Arm cintrol
2025-04-01 Add PCA9548A I2C multiplexer driver implementation
2025-04-01 color sensors working with multiplexer
2025-04-01 Remove unused TCS3472 sensor files and add initial implementation for IR sensor
2025-04-03 Refactor IR sensor handling and update calibration structure: Color sensor working on the robot
2025-04-04 Calibration UI implementation
2025-04-04 stop in a certain distance to a pront waall using Front IR Sensor
2025-04-05 need to fix barcode
    [TCS3472.c, config.c, main.c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]
2025-06-17 Add configuration for water and air pump control

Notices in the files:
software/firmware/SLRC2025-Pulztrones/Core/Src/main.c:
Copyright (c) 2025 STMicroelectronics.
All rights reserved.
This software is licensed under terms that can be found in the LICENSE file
